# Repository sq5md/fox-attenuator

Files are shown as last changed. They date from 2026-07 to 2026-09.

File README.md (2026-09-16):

# Tłumik odbiorczy do łowów na lisa 
Przedmiotem opisu jest urządzenie do tłumienia sygnału pochodzącego z anteny w celu umożliwienia kierunkowego namierzania bliskich urządzeń nadawczych małej mocy takich jak np. nadajniki do łowów na lisa.

Projekt powstał jako potrzeba klubowa SP5YAM z Komorowa.

Autorzy:

Elektronika + oprogramowanie: **Marcin SQ5MD**

Obudowa: **Michał SP5LEL**

Konsultacje: **Klub SP5YAM**

## Zanim zbudujesz

Zanim zbudujesz, miej na uwadze że PCB v1 zawiera błędy i wymaga **cięcia ścieżek**, dolutowania 3 elementów oraz **poprowadzenia 2 cienkich kynarów do układu QFN**.

Projekt PCB v2 w toku.

## Opis głównych funkcji:

- 2 złącza SMA, jedno do podłączenia anteny, drugie do podłączenia odbiornika.
- Zasilanie z 1 ogniwa 18650
- Wbudowana ładowarka 500mA (USB C)
- Sygnalizacja naładowania na diodzie RGB
- Sygnalizacja tłumienia na diodzie RGB oraz na pasku 5xLED
- Interfejs użytkownika - enkoder kwadraturowy (12 imp na obrót) z przyciskiem
- Tłumienie teoretyczne 0-63dB z krokiem co 0,5dB
- Bypass antenowy 50Ω - do namierzania bez kierunku z bardzo bliskiej odległości
- Tłumienie zmierzone: 2.2-64.2dB (bypass do 80dB)
- Auto Power Off po określonym czasie nieaktywności
- Dioda RGB

## Obsługa

Urządzenie po włączeniu jest od razu gotowe do pracy sygnalizując to zaświeceniem diody LED na zielono.
Kręcenie enkoderem powoduje odpowiednio zwiększenie lub zmniejszenie tłumienia z krokiem 0.5dB. 

Stan tłumienia sygnalizowany jest diodą RGB:
- Intensywny zielony - brak tłumienia
- Zielony-poprzez żółty, pomarańczowy, czerwony - aktywne tłumienie w zależności od koloru LED
- Intensywny czerwony - tłumienie maksymalne
- Niebieski - stan odcięcia anteny. Bypass Z=50Ω.

Urządzenie włączamy i wyłączamy przyciskiem na enkoderze.

Urządzenie posiada wbudowaną ładowarkę (MCP73831), a stan naładowania sygnalizowany jest kolorem fioletowym.

Projekt można przetestować na stoisku SP5YAM w Burzeninie 2026 podczas zabawy w łowy na lisa. Dostępne są 2 sztuki.

## Konstrukcja

Tor antenowy układu składa się z poszczególnych elementów (kolejność od strony podłączania odbiornika):
- Złącze SMA (żeńskie)
- RF-Switch AS179 (rozdziela tor odbiorczy na tor antenowy i bypass Z=50Ω)
	- Do anteny: 2 x cyfrowy tłumik regulowany Berex BDA4601 sterowany z mikrokontrolera
	- Bypass: Rezystancja Z=50Ω, pomija oba tłumiki.

 Układ sterowany jest z mikrokontrolera RP2040 (płyta RP2040-Zero od Waveshare https://www.waveshare.com/wiki/RP2040-Zero )

Interfejs użytkownika stanowi enkoder kwadraturowy z przyciskiem, 5 diod LED, dioda LED RGB.

Urządzenie jest zasilane z jednego ogniwa Li-Ion 18650, oraz posiada wbudowaną ładowarkę MCP73831.

Elementy Q1 i D5 pozwalają zrealizować funkcję programowego wyłączenia urządzenia..

### Schemat
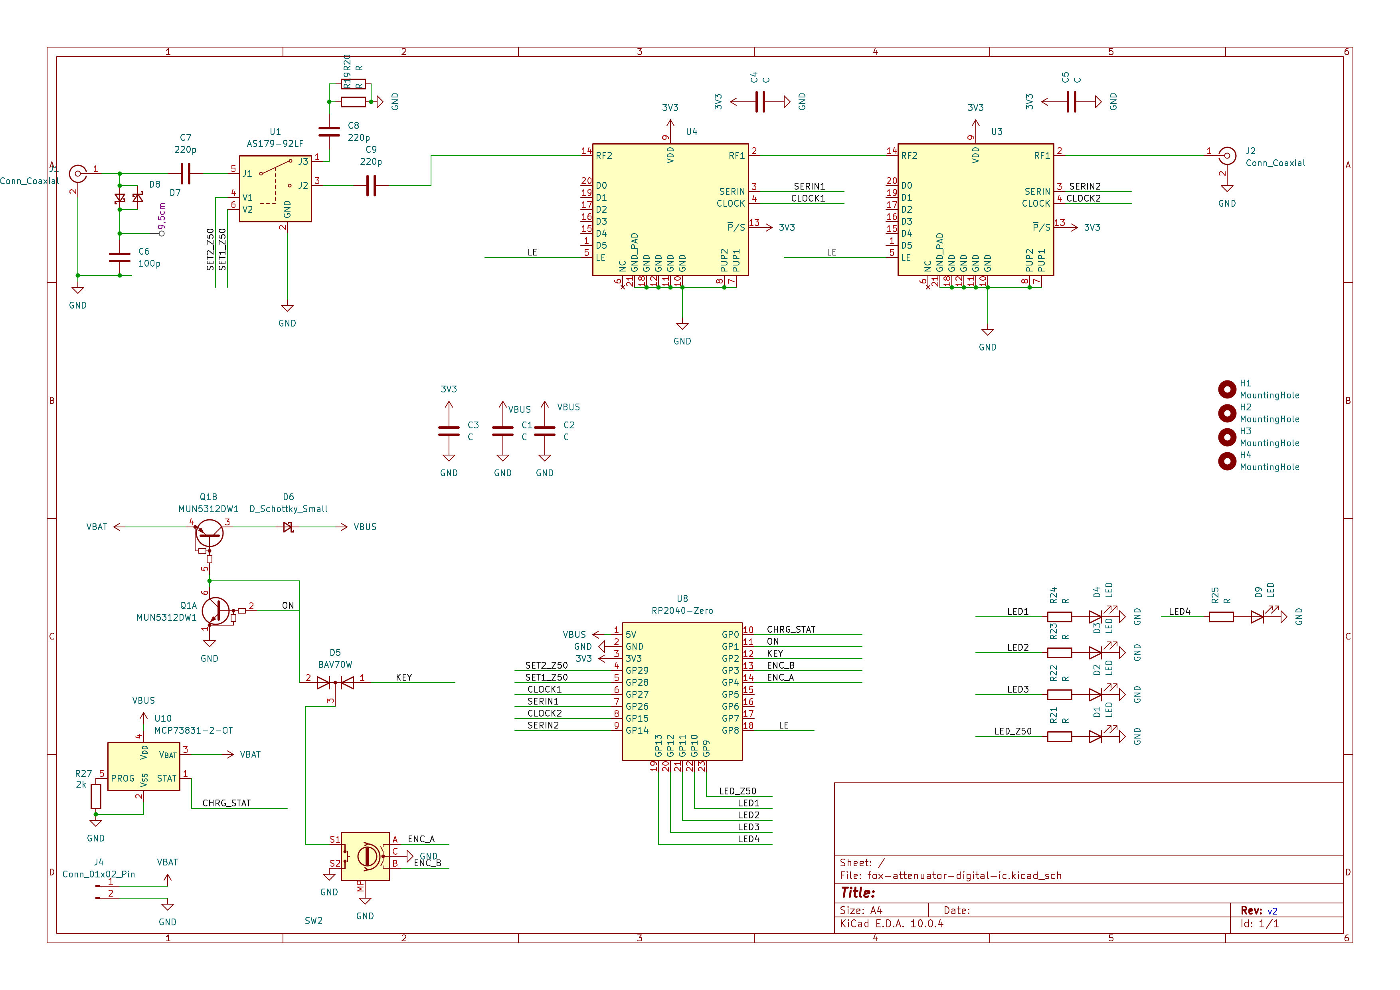
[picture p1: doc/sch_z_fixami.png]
Schemat

### PCB

Płytka drukowana wykonana została w technologii 2 warstwowej na laminacie FR4 o grubości 0.6mm aby zapewnić najlepsze dopasowanie do impedancji 50Ω.

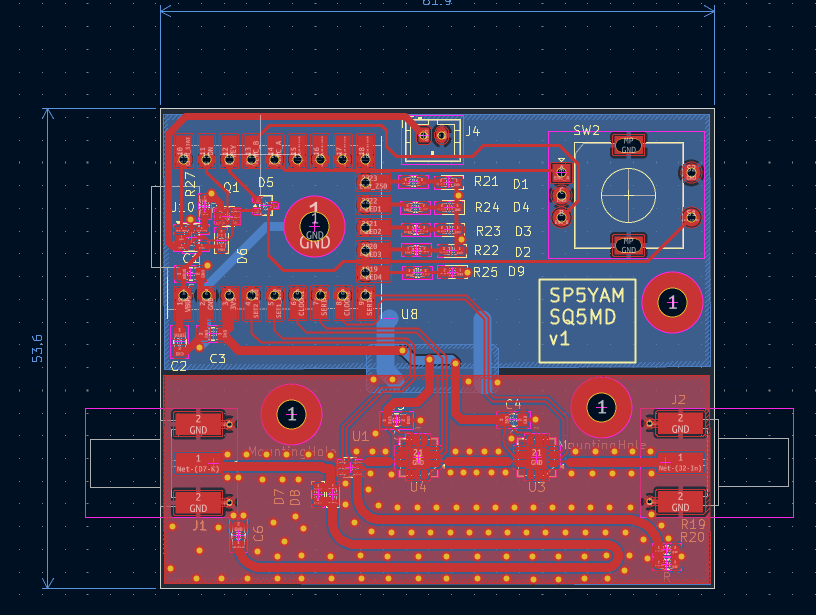
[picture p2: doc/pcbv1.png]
PCB


### Oprogramowanie

#### Moduły

Oprogramowanie układu oparte jest o projekt Zephyr, co przyspieszyło stworzenie projektu. Modułowa konstrukcja oprogramowania pozawala utrzymać porządek i lepiej zrozumieć budowę układu. W układzie można wydzielić kilka głównych modułów które komunikują się ze sobą za pomocą wiadomości wysyłanych przez magistralę EventBus.  
Magistrala EventBus pozwala każdemu z modułów na subskrypcję poszczególnych rodzajów eventów (model Publish/Subscribe).

##### Moduł InputListener

Moduł odpowiada za odpowiedni odczyt eventów z systemu Zephyr i ich wysłanie na magistralę eventów EventBus.
Eventy które wysyła to:
- EncoderRotated(lewo/prawo) - (gdy wykryto przekręcenie enkodera w lewo lub prawo)
- EncoderPressEvent(wciśnięcie/puszczenie) - gdy wyrkryto wciśnięcie lub puszczenie przycisku
- ChargerEvent - gdy wykryto stan naładowania z ładowarki
##### Moduł logiki aplikacji

Obsługuje wiadomości:
- EncoderRotated - wysłanie eventu AttenuatorChange
- EncoderPressEvent - wysłanie eventu PowerOff
- ChargerEvent - wysłanie eventu RgbLedSet()
- AttenuationInfo - wysłanie eventu RgbLedSet oraz LedMatrixSet w zależności od wartości tłumienia

##### Moduł HW
Obsługuje wiadomości:
- LedMatrixSet - ustawienie stanu na diodach 5xLED
- PowerOff - wyłączenie układu
- RgbLedSet - ustawienie odpowiedniego koloru na diodzie RGB
- ApplyAttenuatorChange - zmiana tłumienia (lub bypass)

#### Bootloader
Mikrokontroler posiada wbudowany bootloader.
Aktualizacja oprogramowania jest możliwa za pomocą przewodu USB-C.
Jest to standardowy bootloader wbudowany w mikrokontroler RP2040.

### Obudowa

Do układu powstała obudowa wykonana w technologii druku 3D FDM, autorem obudowy jest Michał SP5LEL.
Na moment pisania tej treści nie ma dostępnych fotografii obudowy.

### Fotografie

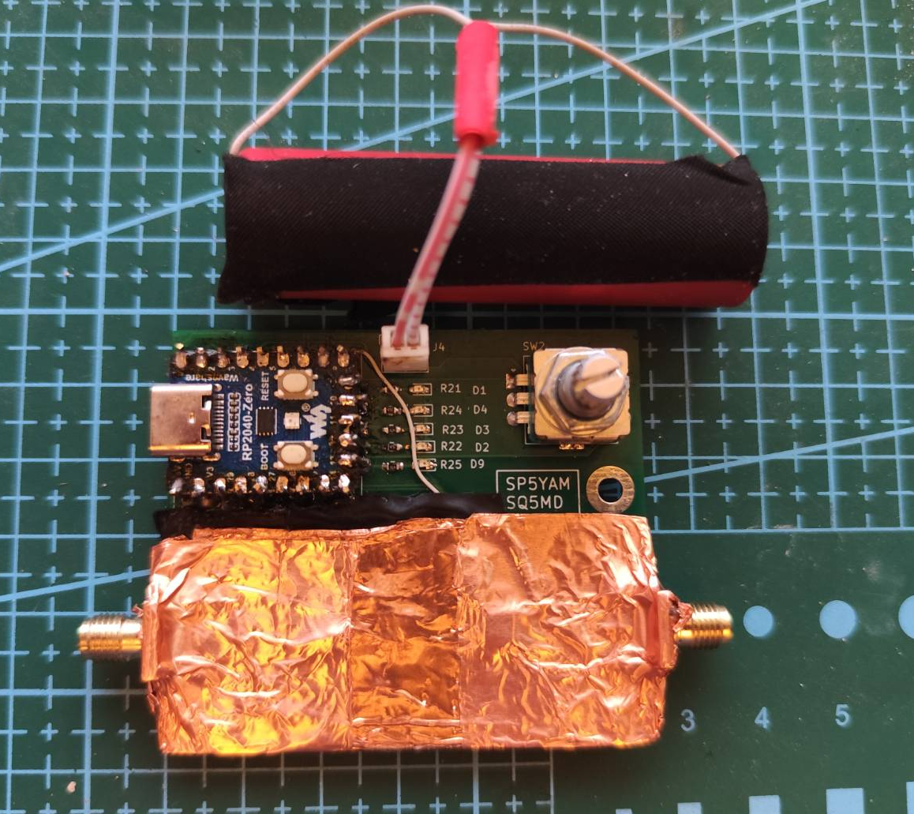
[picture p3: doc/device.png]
Urządzenie


## Pomiary

Urządzenie pomiarowe:
NanoVNA V2 od NanoRFE (https://nanorfe.com/pl/)
Aplikacja:
VNA_View na Linux

Parametry pomiarowe:
Sweep 144-440MHz, 1024 punkty, AVG=5
kalibracja SOLT

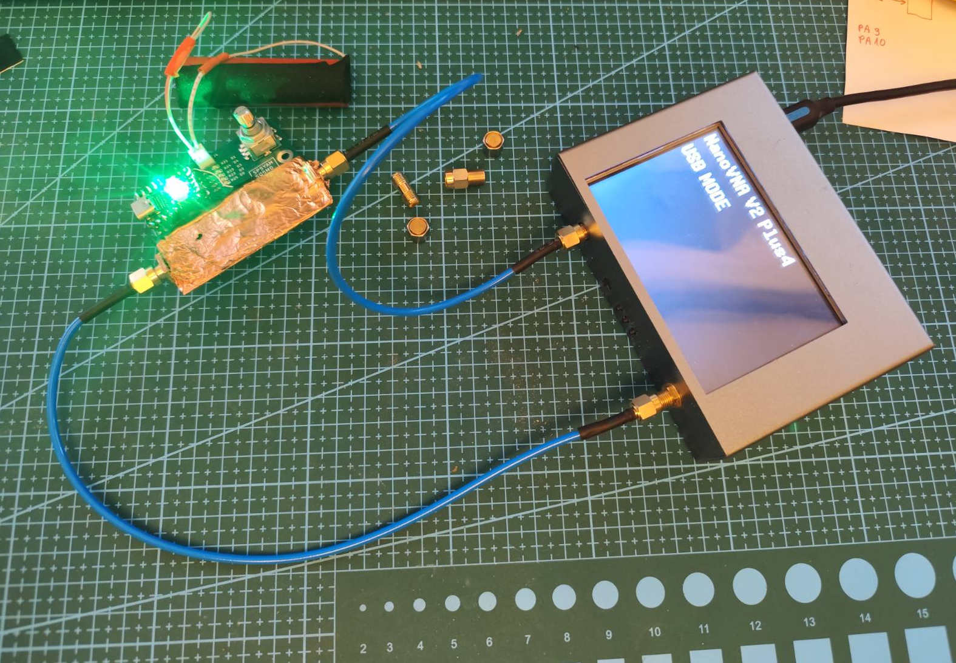
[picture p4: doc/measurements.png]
Pomiary


### Minimalne tłumienie
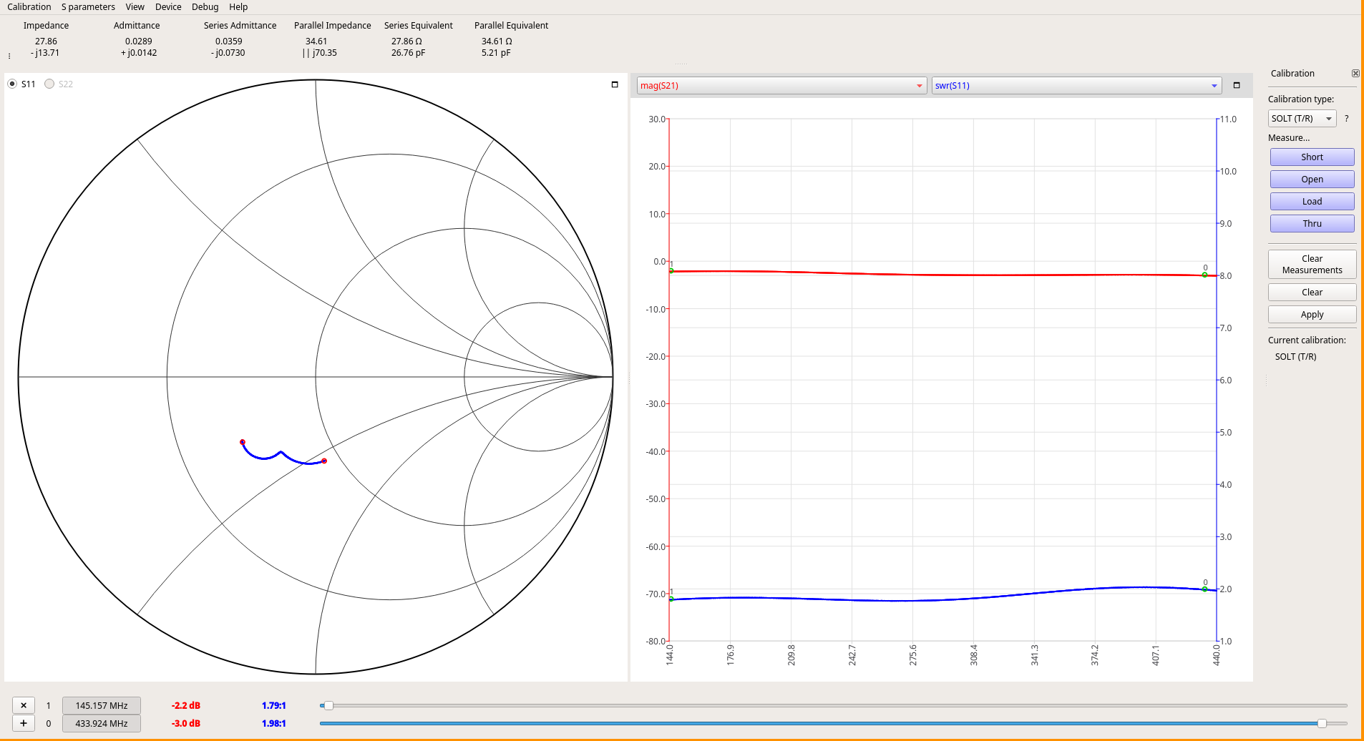
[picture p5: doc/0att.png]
Minimalne tłumienie

### Połowa skali
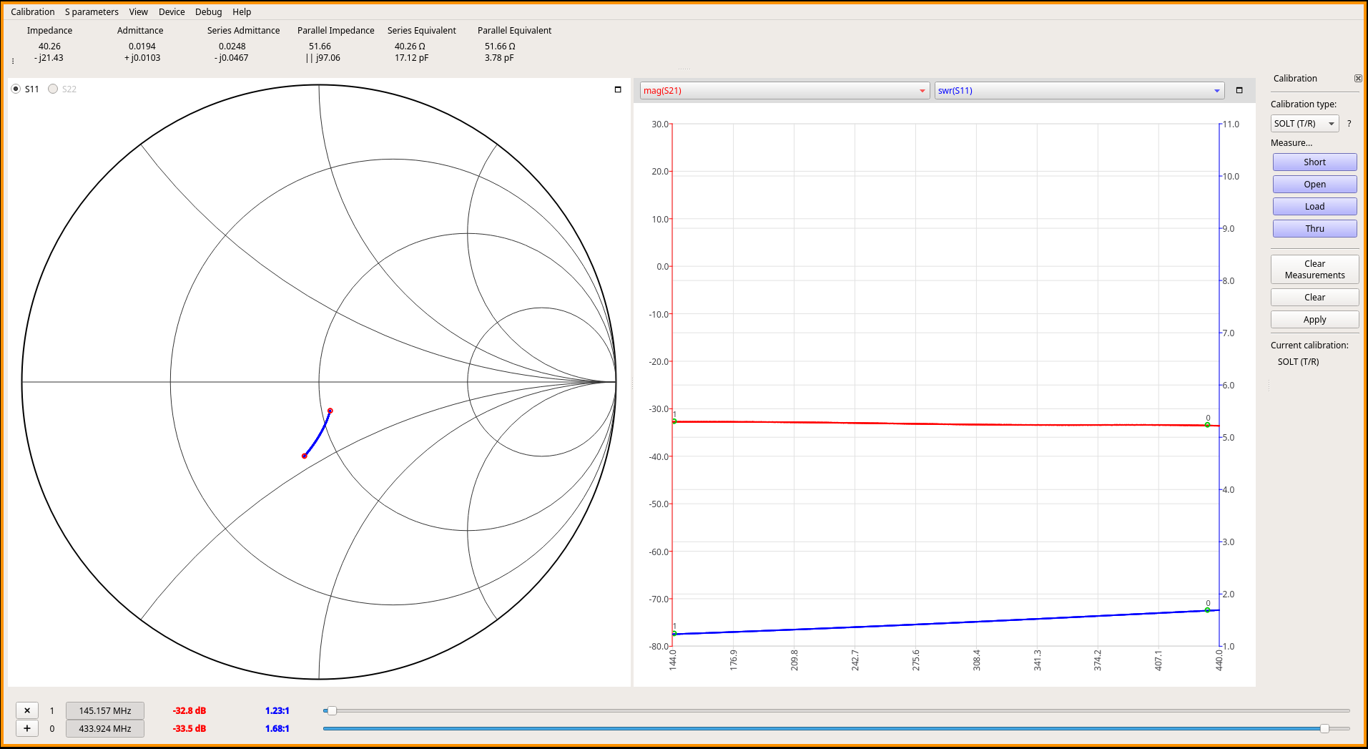
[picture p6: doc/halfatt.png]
Połowa tłumienia

### Maksymalne tłumienie
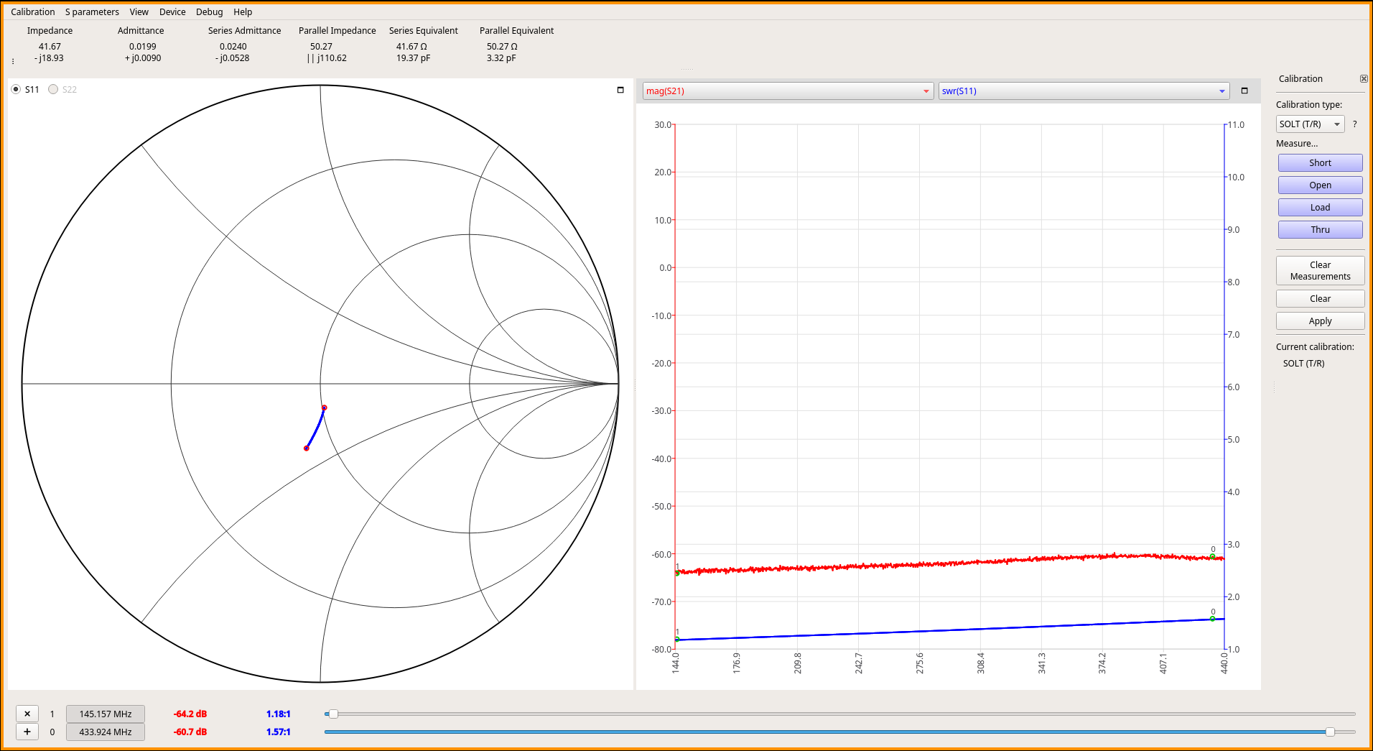
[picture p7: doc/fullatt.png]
Maksymalne tłumienie

### Bypass
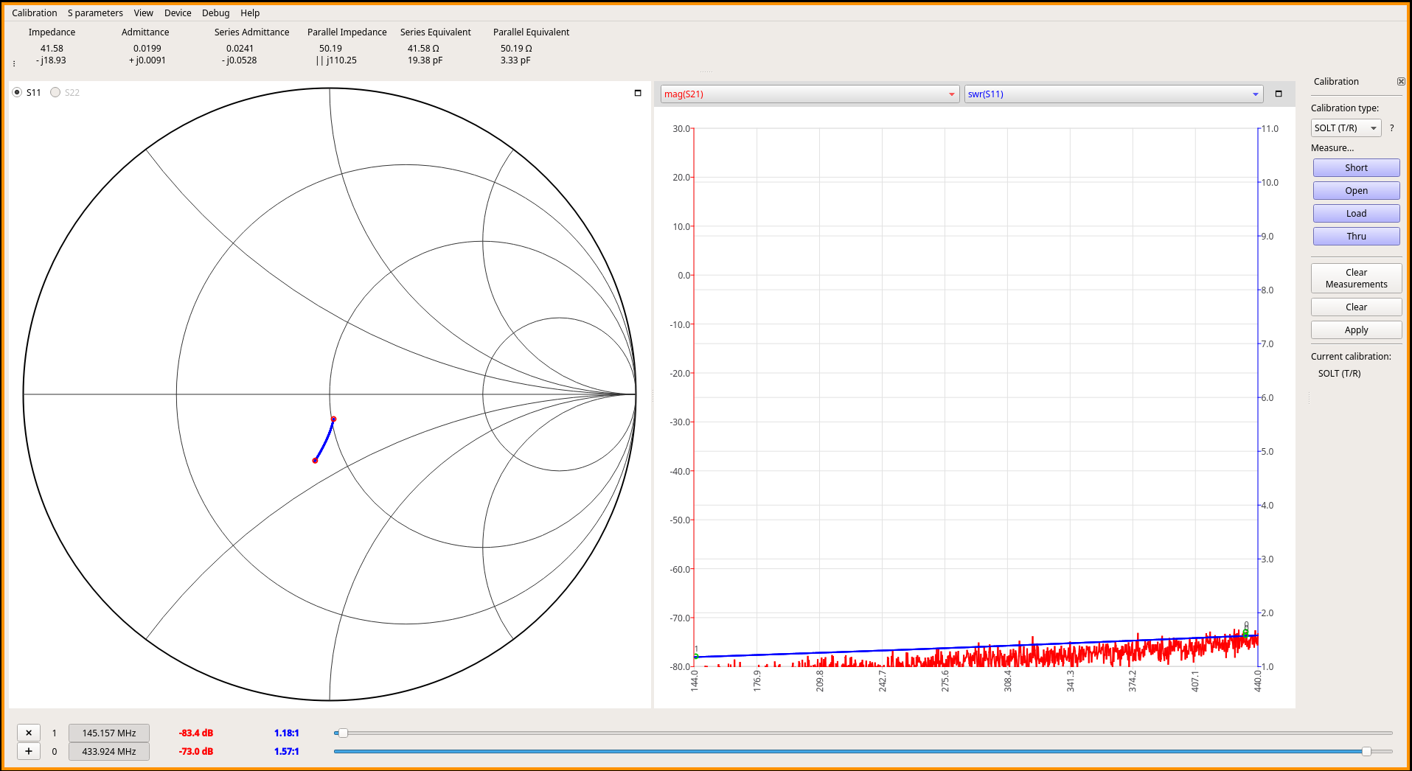
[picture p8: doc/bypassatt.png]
Bypass antenowy


Tor bypassu jest najbardziej wrażliwy na ekranowanie urządzenia.

## TODO:

- [ ] Poprawki PCB: brak sygnału LE, brak DC-blockerów RF
- [ ] Diody LED THT zamiast SMD
- [ ] Tylko jeden tłumik regulowany, drugi stały 30dB
- [ ] Wymiana ładowarki jest bardzo trudna - montować układ inaczej
- [ ] Integracja z odbiornikiem (żeby nie trzeba było podłączać zewnętrznego odbiornika)
- [ ] Dodać pomiar napięcia baterii
- [ ] Wrzucić do releases plik uf2

## Przeróbka PCB v1 aby działała

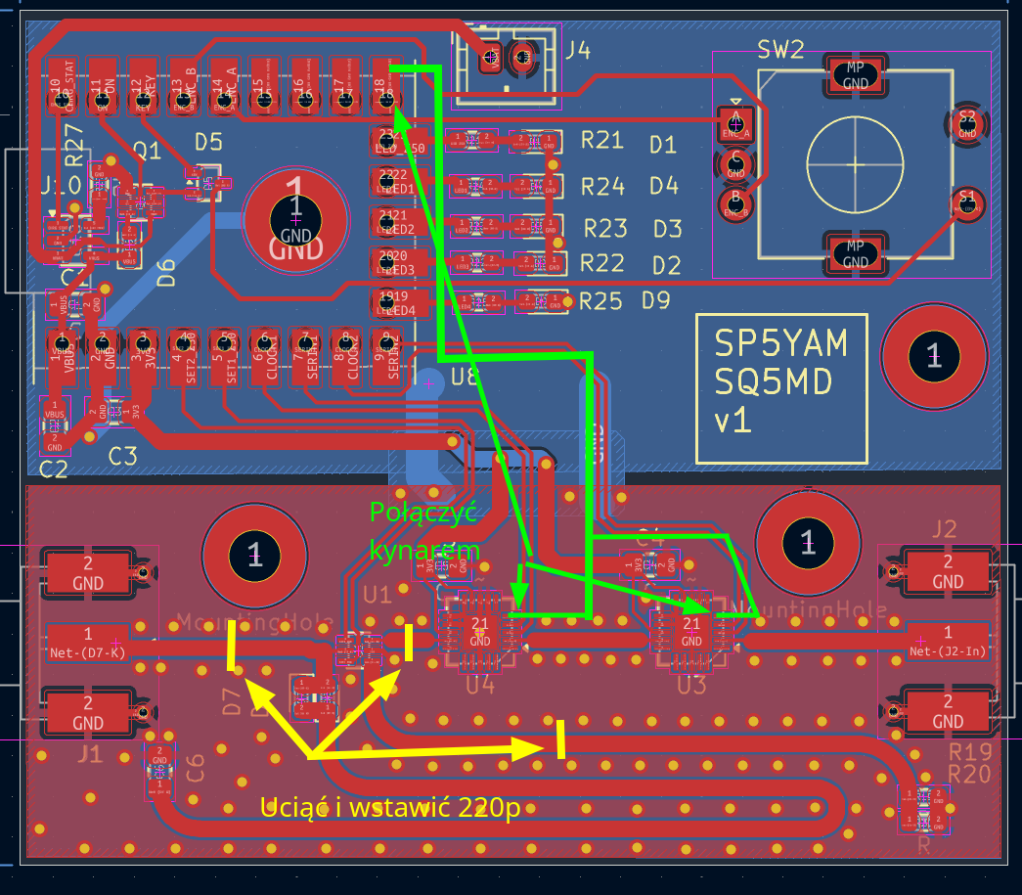
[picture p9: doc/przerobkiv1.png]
Przeróbka v1


## Edytor schematów i pcb

Stworzone w Kicad 10.0.4

## Jak skompilować

1. Zainstaluj Zephyra: https://docs.zephyrproject.org/latest/develop/getting_started/index.html
2. Zainstaluj i skonfiguruj CLion: https://docs.zephyrproject.org/latest/develop/tools/clion.html
3. Otwórz projekt in CLion, otwórz folder w którym znajduje się główny plik CMakeLists.txt (w momencie pisania tej treści jest to folder 'software/fox-attenuator')
4. Uruchom płytkę RP2040-Zero w trybie bootloadera a następnie wybierz target "flash" w CLion i uruchom budowanie projektu.

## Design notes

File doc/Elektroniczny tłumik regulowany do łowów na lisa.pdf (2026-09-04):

## Elektroniczny tłumik regulowany do łowów na lisa

Przedmiotem opisu jest urządzenie do tłumienia sygnału pochodzącego z anteny w celu umożliwienia kierunkowego namierzania bliskich urządzeń nadawczych małej mocy takich jak np. nadajniki do łowów na lisa.
Projekt powstał jako potrzeba klubowa SP5YAM z Komorowa.

Autorzy:
Elektronika + oprogramowanie: Marcin SQ5MD
Obudowa: Michał SP5LEL
Konsultacje: Klub SP5YAM

Link: https://github.com/sq5md/fox-attenuator

## Opis głównych funkcji:

## Obsługa

Urządzenie po włączeniu jest od razu gotowe do pracy sygnalizując to zaświeceniem diody LED na zielono.
Kręcenie enkoderem powoduje odpowiednio zwiększenie lub zmniejszenie tłumienia z krokiem 0.5dB.

Stan tłumienia sygnalizowany jest diodą RGB:

Urządzenie włączamy i wyłączamy przyciskiem na enkoderze.

2 złącza SMA, jedno do podłączenia anteny, drugie do podłączenia odbiornika. Zasilanie z 1 ogniwa 18650
Wbudowana ładowarka 500mA (USB C)
Sygnalizacja naładowania na diodzie RGB
Sygnalizacja tłumienia na diodzie RGB oraz na pasku 5xLED
Interfejs użytkownika - enkoder kwadraturowy (12 imp na obrót) z przyciskiem Tłumienie teoretyczne 0-63dB z krokiem co 0,5dB
Bypass antenowy 50Ω - do namierzania bez kierunku z bardzo bliskiej odległości Tłumienie zmierzone: 2.2-64.2dB (bypass do 80dB)
Auto Power Off po określonym czasie nieaktywności
Dioda RGB

Intensywny zielony - brak tłumienia
Zielony-poprzez żółty, pomarańczowy, czerwony - aktywne tłumienie w zależności od koloru LED
Intensywny czerwony - tłumienie maksymalne
Niebieski - stan odcięcia anteny. Bypass Z=50Ω.

Urządzenie posiada wbudowaną ładowarkę (MCP73831), a stan naładowania sygnalizowany jest kolorem fioletowym.

Projekt można przetestować na stoisku SP5YAM w Burzeninie 2026 podczas zabawy w łowy na lisa. Dostępne są 2 sztuki.

## Konstrukcja

Tor antenowy układu składa się z poszczególnych elementów (kolejność od strony podłączania odbiornika):

Układ sterowany jest z mikrokontrolera RP2040 (płyta RP2040-Zero od Waveshare https://www.waveshare.com/wiki/RP2040-Zero )

Interfejs użytkownika stanowi enkoder kwadraturowy z przyciskiem, 5 diod LED, dioda LED RGB.

Urządzenie jest zasilane z jednego ogniwa Li-Ion 18650, oraz posiada wbudowaną ładowarkę MCP73831.

Elementy Q1 i D5 pozwalają zrealizować funkcję programowego wyłączenia urządzenia..

### Schemat

Złącze SMA (żeńskie)
RF-Switch AS179 (rozdziela tor odbiorczy na tor antenowy i bypass Z=50Ω) Do anteny: 2 x cyfrowy tłumik regulowany Berex BDA4601 sterowany z mikrokontrolera
Bypass: Rezystancja Z=50Ω, pomija oba tłumiki.

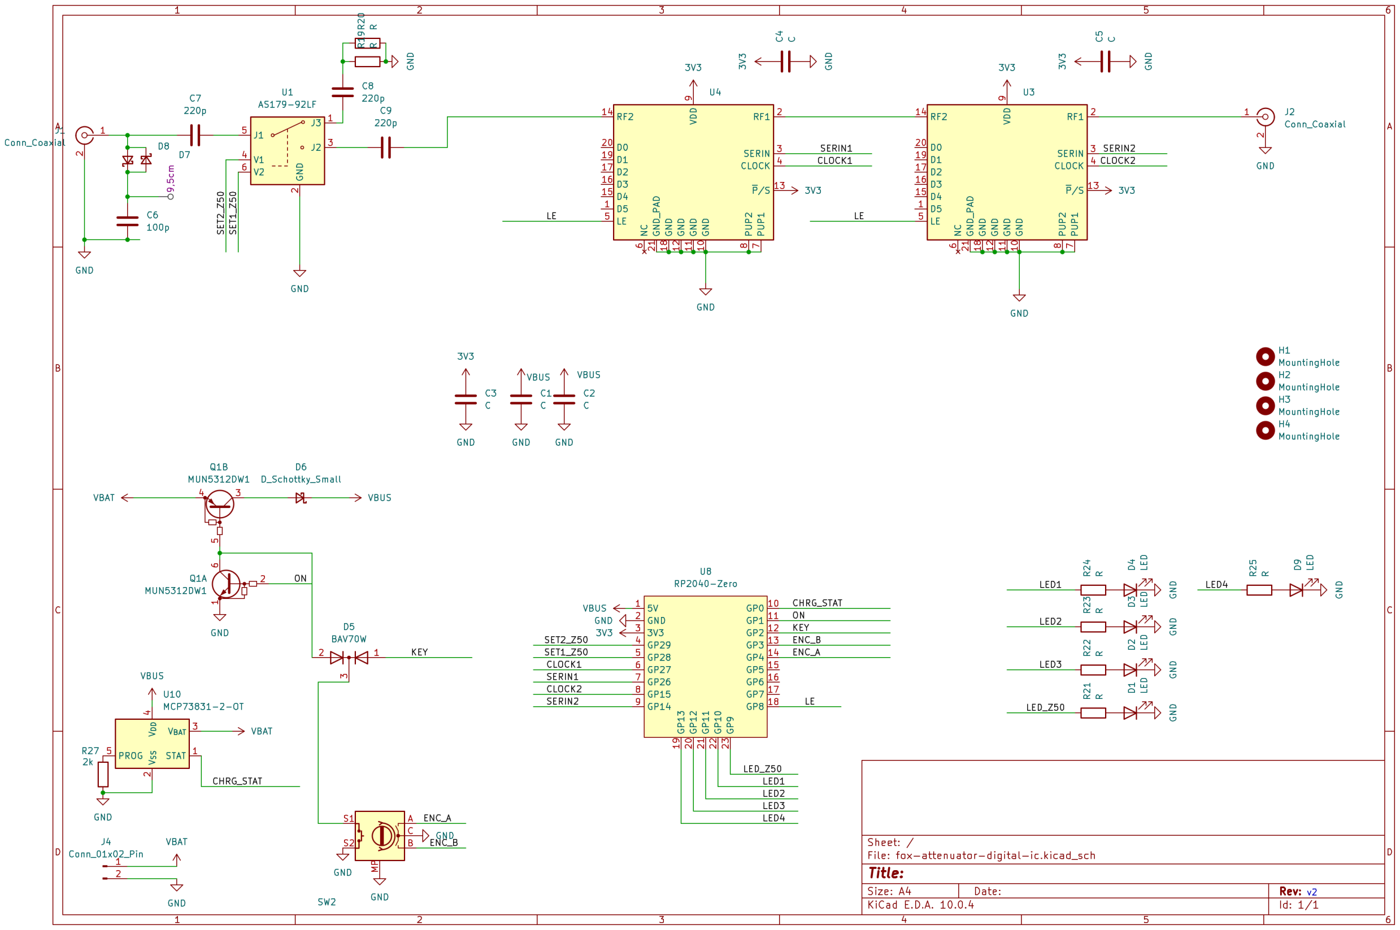
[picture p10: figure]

### PCB

Płytka drukowana wykonana została w technologii 2 warstwowej na laminacie FR4 o grubości 0.6mm aby zapewnić najlepsze dopasowanie do impedancji 50Ω.

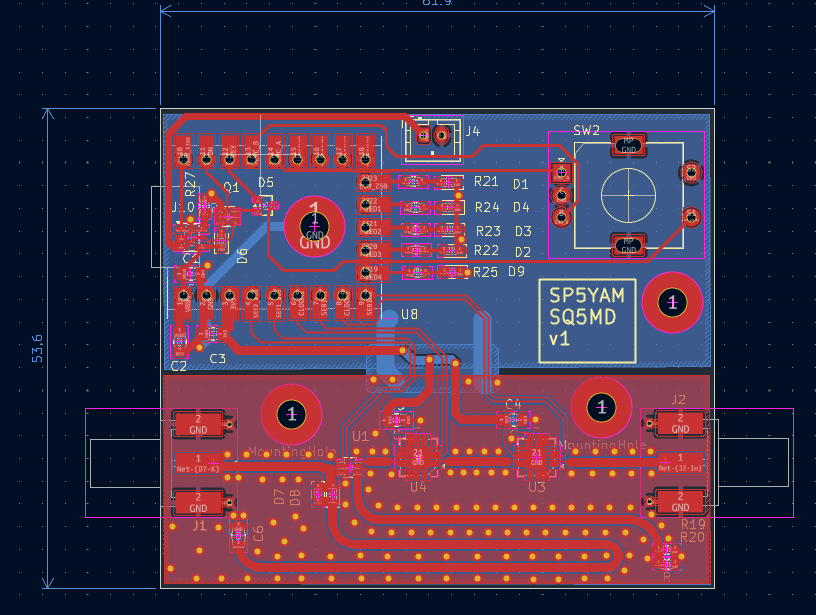
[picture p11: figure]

### Oprogramowanie

### Moduły

Oprogramowanie układu oparte jest o projekt Zephyr, co przyspieszyło stworzenie projektu. Modułowa konstrukcja oprogramowania pozawala utrzymać porządek i lepiej zrozumieć budowę układu. W układzie można wydzielić kilka głównych modułów które komunikują się ze sobą za pomocą wiadomości wysyłanych przez magistralę EventBus.
Magistrala EventBus pozwala każdemu z modułów na subskrypcję poszczególnych rodzajów eventów (model Publish/Subscribe).

Moduł InputListener

Moduł odpowiada za odpowiedni odczyt eventów z systemu Zephyr i ich wysłanie na magistralę eventów EventBus.
Eventy które wysyła to:

Moduł logiki aplikacji

EncoderRotated(lewo/prawo) - (gdy wykryto przekręcenie enkodera w lewo lub prawo) EncoderPressEvent(wciśnięcie/puszczenie) - gdy wyrkryto wciśnięcie lub puszczenie przycisku
ChargerEvent - gdy wykryto stan naładowania z ładowarki

Obsługuje wiadomości:

Moduł HW

Obsługuje wiadomości:

### Bootloader

Mikrokontroler posiada wbudowany bootloader.
Aktualizacja oprogramowania jest możliwa za pomocą przewodu USB-C. Jest to standardowy bootloader wbudowany w mikrokontroler RP2040.

### Obudowa

Do układu powstała obudowa wykonana w technologii druku 3D FDM, autorem obudowy jest Michał SP5LEL.
Na moment pisania tej treści nie ma dostępnych fotografii obudowy.

### Fotografie

EncoderRotated - wysłanie eventu AttenuatorChange
EncoderPressEvent - wysłanie eventu PowerOff
ChargerEvent - wysłanie eventu RgbLedSet()
AttenuationInfo - wysłanie eventu RgbLedSet oraz LedMatrixSet w zależności od wartości tłumienia

LedMatrixSet - ustawienie stanu na diodach 5xLED
PowerOff - wyłączenie układu
RgbLedSet - ustawienie odpowiedniego koloru na diodzie RGB ApplyAttenuatorChange - zmiana tłumienia (lub bypass)

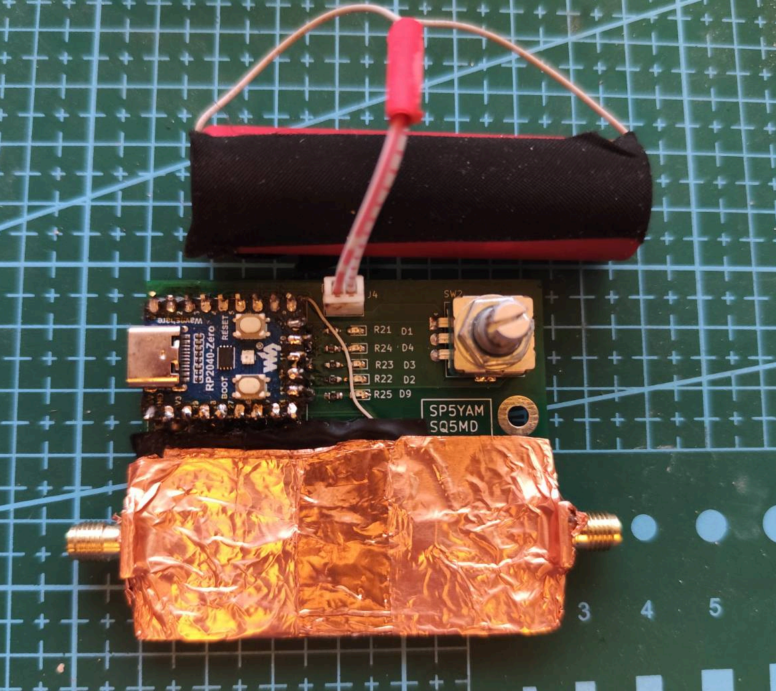
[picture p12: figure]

## Pomiary

Urządzenie pomiarowe:
NanoVNA V2 od NanoRFE (https://nanorfe.com/pl/) Aplikacja:
VNA_View na Linux

Parametry pomiarowe:
Sweep 144-440MHz, 1024 punkty, AVG=5 kalibracja SOLT

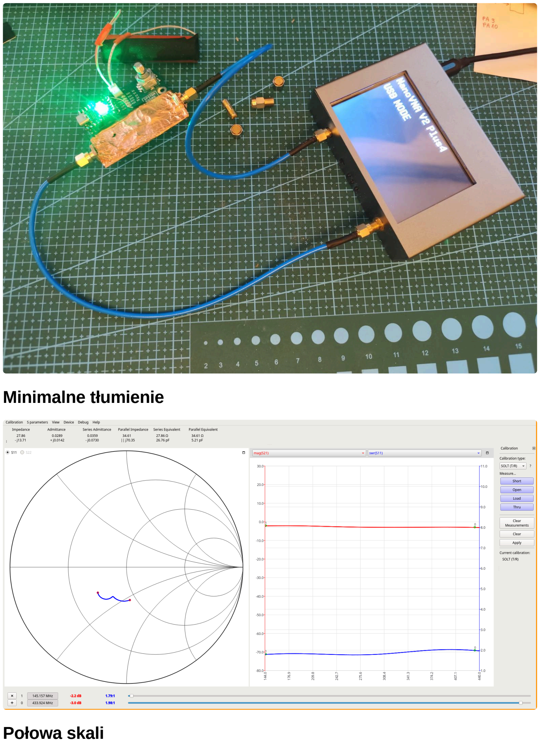
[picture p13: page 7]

### Minimalne tłumienie

### Połowa skali

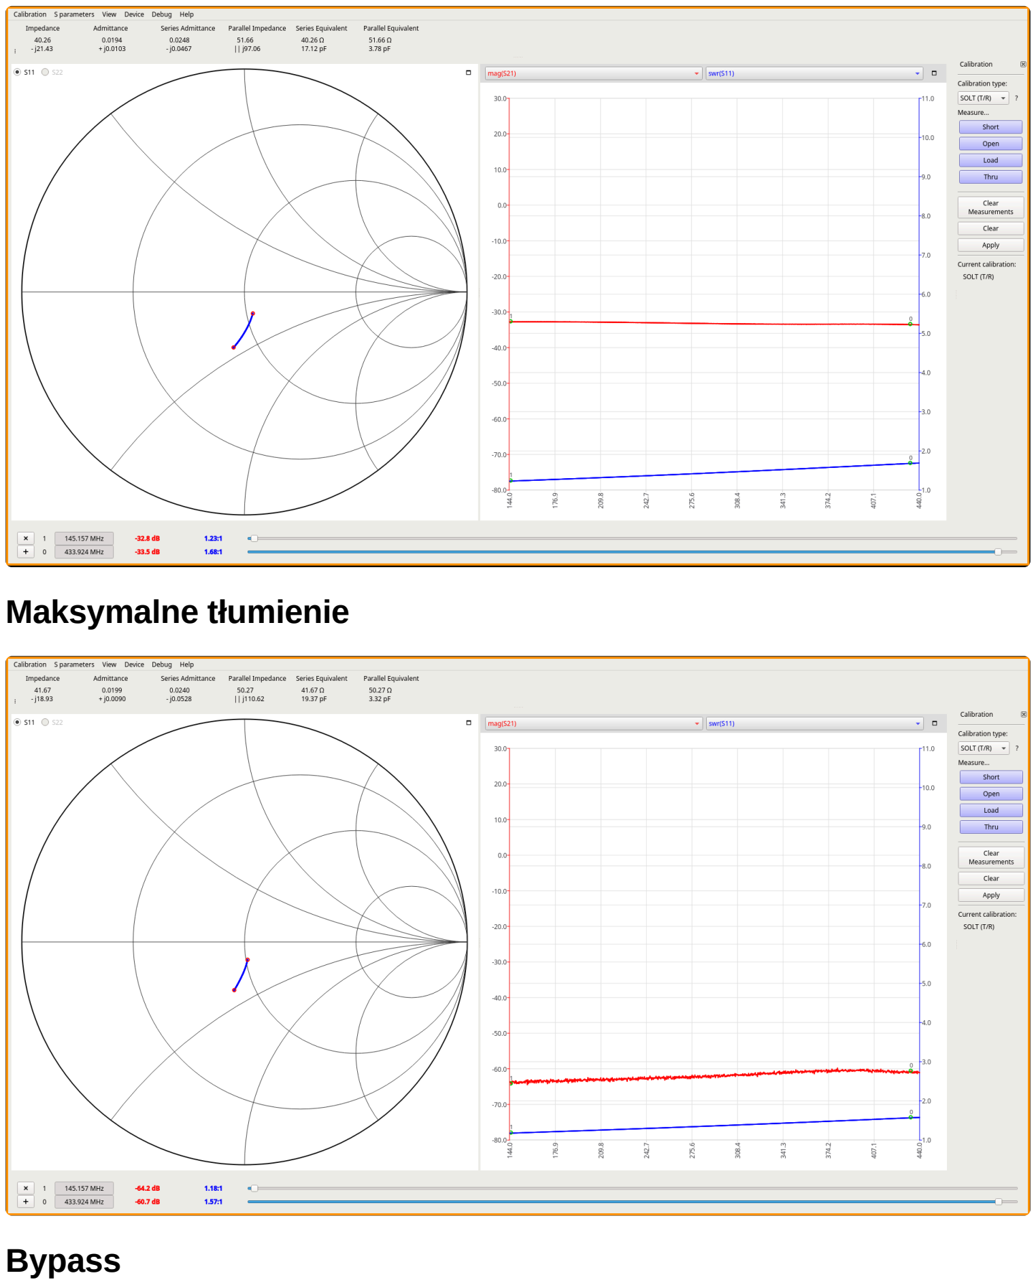
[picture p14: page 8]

### Maksymalne tłumienie

### Bypass

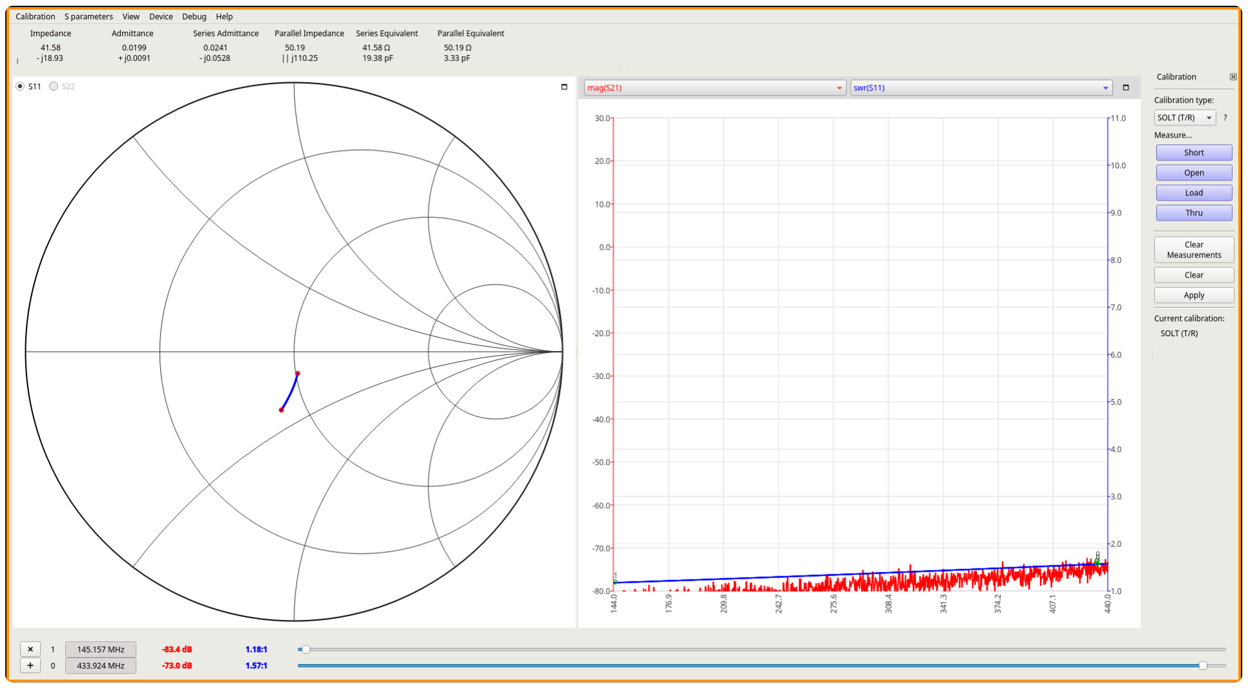
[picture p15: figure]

Tor bypassu jest najbardziej wrażliwy na ekranowanie urządzenia.

## Plany na przyszłość

Poprawki PCB: brak sygnału LE, brak DC-blockerów RF
Diody LED THT zamiast SMD
Tylko jeden tłumik regulowany, drugi stały 30dB
Wymiana ładowarki jest bardzo trudna - montować układ inaczej
Integracja z odbiornikiem (żeby nie trzeba było podłączać zewnętrznego odbiornika) Dodać pomiar napięcia baterii

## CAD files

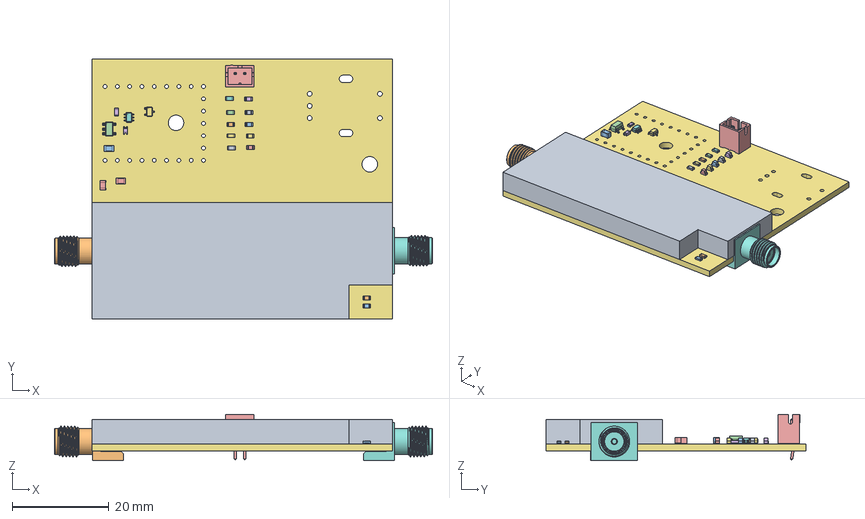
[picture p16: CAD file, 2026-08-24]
3d/shield.FCStd
78.0 x 53.6 x 9.58 mm
SMA_Molex_73251-1153_EdgeMount_Horizontal
LED_0603_1608Metric
D_0603
C_0805_2012Metric
D_0604
SOT-323_SC-70
SMA_Molex_73251-1153_EdgeMount_Horizontal002
D_0605
R_0603_1608Metric
SOT-363_SC-70-6
R_0603_1608Metric002
C_0805_2012Metric002
LED_0603_1608Metric002
LED_0603_1608Metric004
SOT-363_SC-70-002
R_0603_1608Metric004
R_0603_1608Metric006
C_0805_2012Metric004
SOT-23-5
LED_0603_1608Metric006
R_0603_1608Metric008
R_0603_1608Metric010
R_0603_1608Metric012
LED_0603_1608Metric008
C_0805_2012Metric006
R_0603_1608Metric014
C_0805_2012Metric008
JST_B2B_PH_K
C_0805_2012Metric010
fox-attenuator-digital-ic_PCB

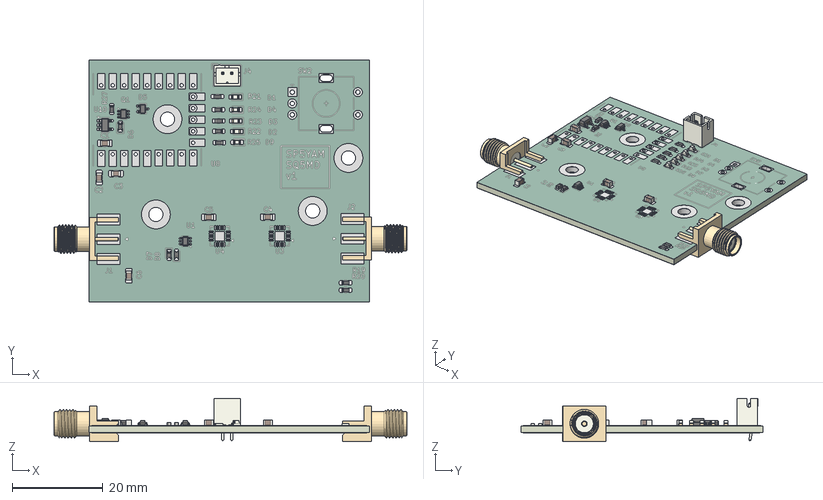
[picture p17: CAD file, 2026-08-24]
3d/fox-attenuator-v1.step
78.0 x 53.6 x 9.58 mm
SMA_Molex_73251-1153_EdgeMount_Horizontal x 2
LED_0603_1608Metric x 5
D_0603 x 3
C_0805_2012Metric x 6
SOT-323_SC-70
R_0603_1608Metric x 8
SOT-363_SC-70-6 x 2
SOT-23-5
JST_B2B_PH_K
fox-attenuator-digital-ic_copper
fox-attenuator-digital-ic_pad
fox-attenuator-digital-ic_via
fox-attenuator-digital-ic_silkscreen
fox-attenuator-digital-ic_soldermask x 2
fox-attenuator-digital-ic_PCB

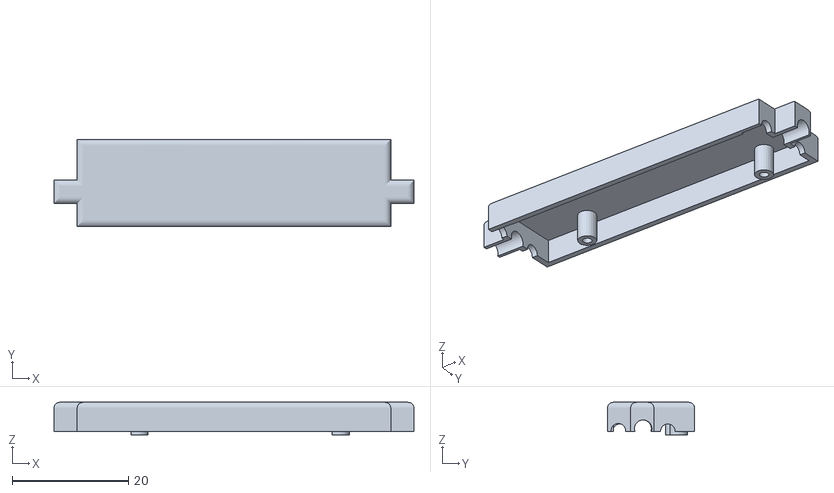
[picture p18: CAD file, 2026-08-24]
3d/shield-Body.stl
62.0 x 15.0 x 5.60

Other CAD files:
3d/shield_simple.FCStd

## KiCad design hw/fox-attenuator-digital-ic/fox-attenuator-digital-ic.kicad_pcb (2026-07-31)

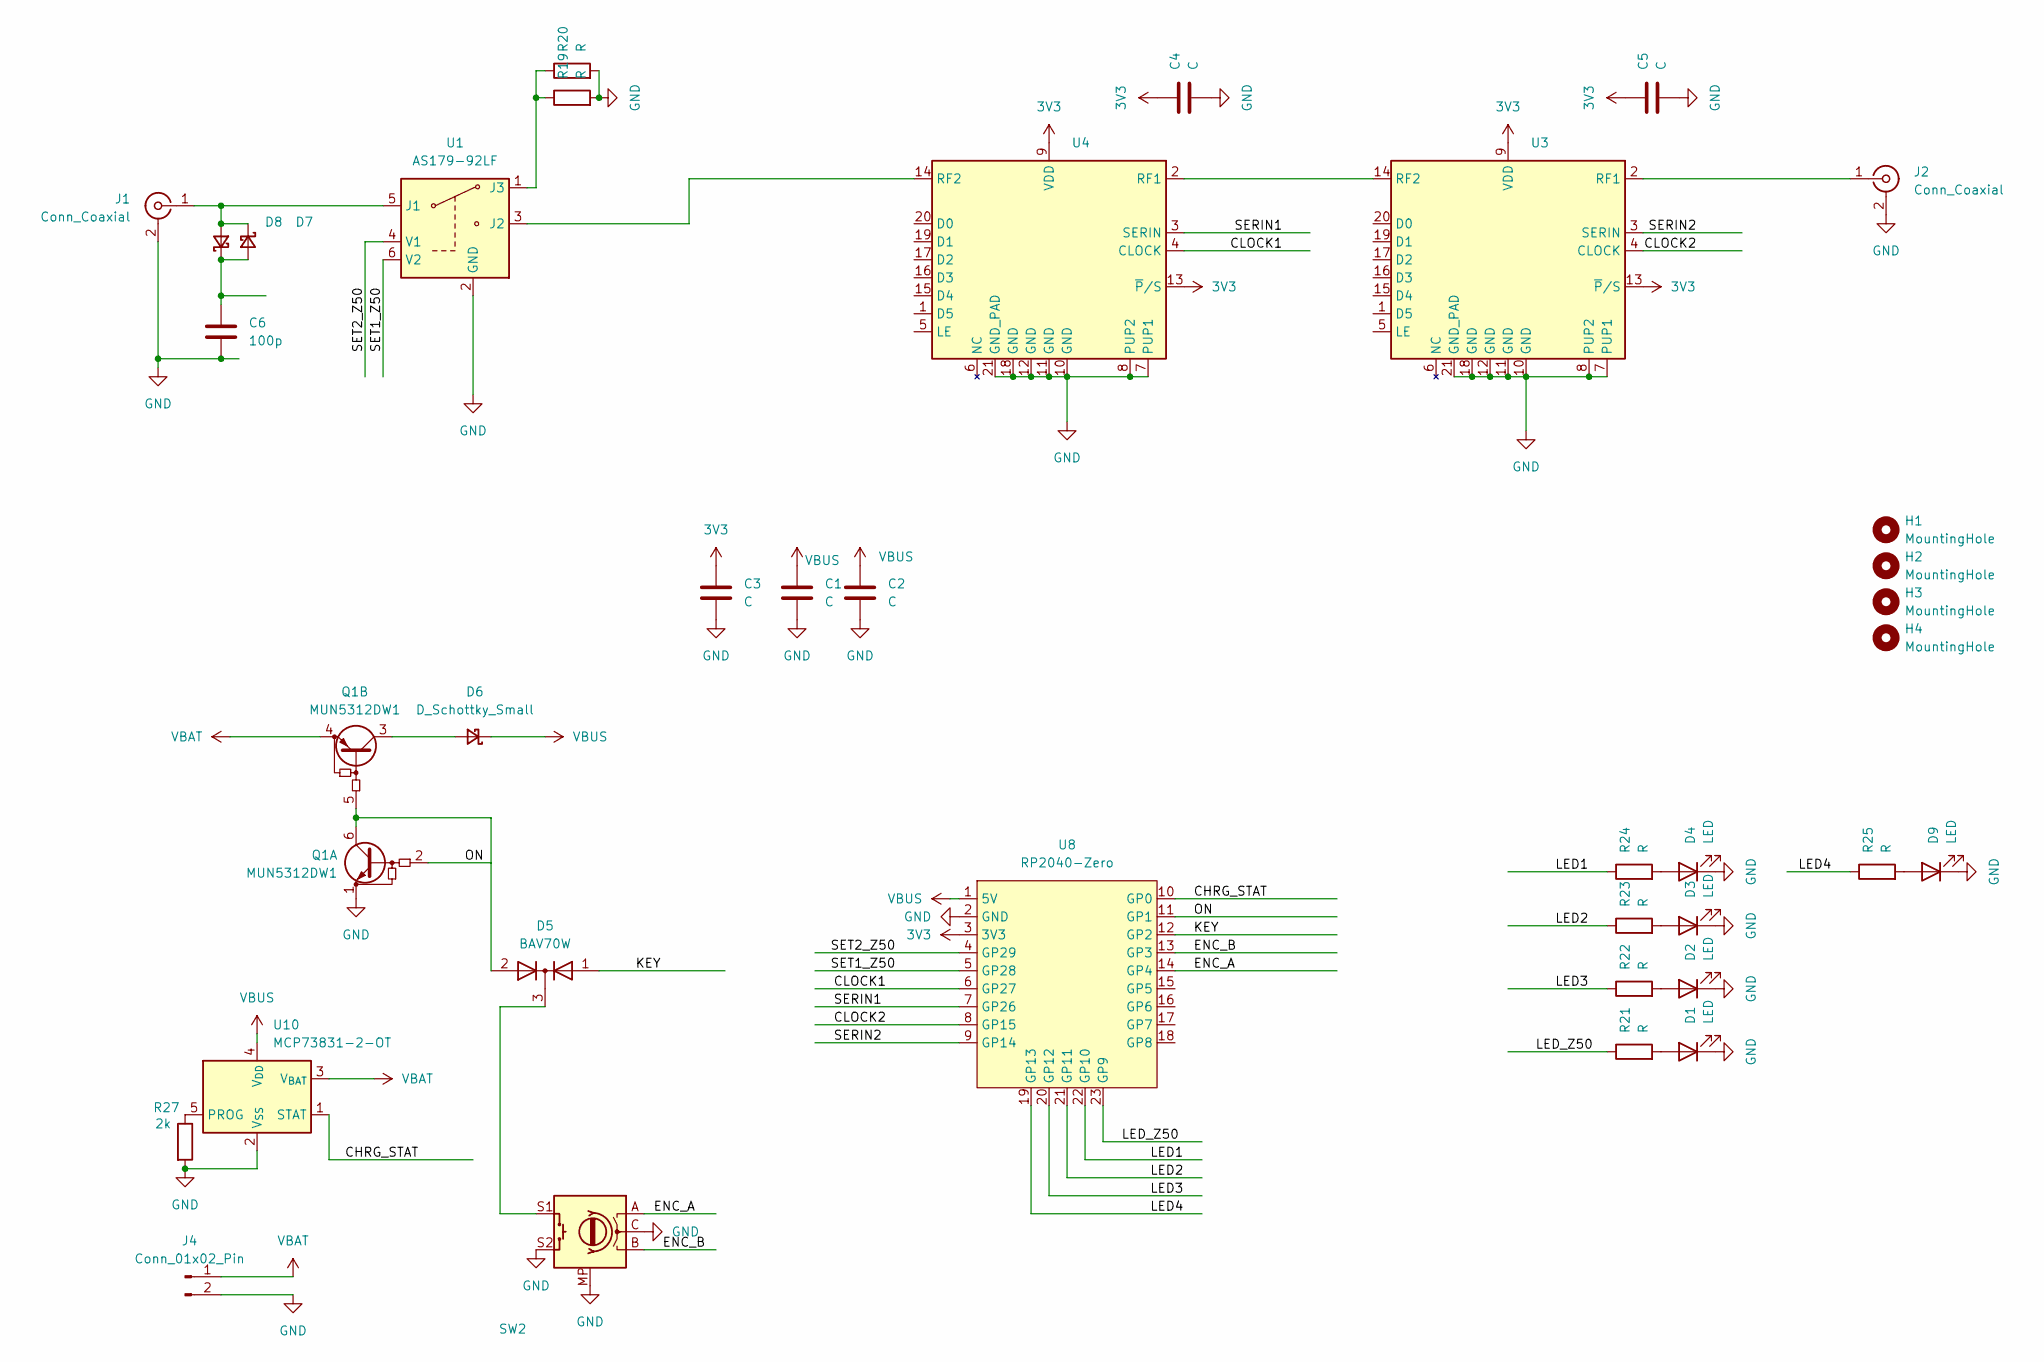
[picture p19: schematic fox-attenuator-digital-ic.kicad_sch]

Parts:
C1, C2, C3, C4, C5: C; C_0805_2012Metric_Pad1.18x1.45mm_HandSolder
C6: 100p; C_0805_2012Metric_Pad1.18x1.45mm_HandSolder
D1, D2, D3, D4, D9: LED; LED_0603_1608Metric_Pad1.05x0.95mm_HandSolder
D5: BAV70W; SOT-323_SC-70
D6, D7, D8: D_Schottky_Small; D_0603_1608Metric
H1, H2, H3, H4: MountingHole; MountingHole_3.2mm_M3_Pad_TopBottom
J1, J2: Conn_Coaxial; SMA_Molex_73251-1153_EdgeMount_Horizontal
J4: Conn_01x02_Pin; JST_PH_B2B-PH-K_1x02_P2.00mm_Vertical
Q1: MUN5312DW1; SOT-363_SC-70-6
R19, R20, R21, R22, R23, R24, R25: R; R_0603_1608Metric_Pad0.98x0.95mm_HandSolder
R27: 2k; R_0603_1608Metric
SW2: RotaryEncoder_Switch_MP; RotaryEncoder_Alps_EC11E-Switch_Vertical_H20mm
U1: AS179-92LF; SOT-363_SC-70-6
U3, U4: TQFN-20-1EP_4x4mm_P0.5mm_EP2.1x2.1mm
U8: RP2040-Zero; RP2040 Zero
U10: MCP73831-2-OT; SOT-23-5

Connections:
3V3: C3.1, C4.1, C5.1, U3.9 (VDD), U3.13 (~P/S), U4.9 (VDD), U4.13 (~P/S), U8.3 (3V3)
/CHRG_STAT: U8.10 (GP0), U10.1 (STAT)
/CLOCK1: U4.4 (CLOCK), U8.6 (GP27)
/CLOCK2: U3.4 (CLOCK), U8.8 (GP15)
/ENC_A: SW2.A, U8.14 (GP4)
/ENC_B: SW2.B, U8.13 (GP3)
/KEY: D5.1 (A), U8.12 (GP2)
/LED1: R24.1, U8.22 (GP10)
/LED2: R23.1, U8.21 (GP11)
/LED3: R22.1, U8.20 (GP12)
/LED4: R25.1, U8.19 (GP13)
/LED_Z50: R21.1, U8.23 (GP9)
/ON: Q1.2 (B1), U8.11 (GP1)
/SERIN1: U4.3 (SERIN), U8.7 (GP26)
/SERIN2: U3.3 (SERIN), U8.9 (GP14)
/SET1_Z50: U1.6 (V2), U8.5 (GP28)
/SET2_Z50: U1.4 (V1), U8.4 (GP29)
GND: C1.2, C2.2, C3.2, C4.2, C5.2, C6.2, D1.1 (K), D2.1 (K), D3.1 (K), D4.1 (K), D9.1 (K), H3.1, J1.2 (Ext), J2.2 (Ext), J4.2, Q1.1 (E1), R19.2, R20.2, R27.2, SW2.C, SW2.MP, SW2.S2, U1.2 (GND), U3.7 (PUP1), U3.8 (PUP2), U3.10 (GND), U3.11 (GND), U3.12 (GND), U3.18 (GND), U3.21 (GND_PAD), U4.7 (PUP1), U4.8 (PUP2), U4.10 (GND), U4.11 (GND), U4.12 (GND), U4.18 (GND), U4.21 (GND_PAD), U8.2 (GND), U10.2 (V_{SS})
unnamed: D1.2 (A), R21.2
unnamed: D2.2 (A), R22.2
unnamed: D3.2 (A), R23.2
unnamed: D4.2 (A), R24.2
unnamed: D5.3 (K), SW2.S1
unnamed: D6.2 (A), Q1.3 (C2)
unnamed: C6.1, D7.2 (A), D8.1 (K)
unnamed: D7.1 (K), D8.2 (A), J1.1 (In), U1.5 (J1)
unnamed: D9.2 (A), R25.2
unnamed: J2.1 (In), U3.2 (RF1)
unnamed: D5.2 (A), Q1.5 (B2), Q1.6 (C1)
unnamed: U1.3 (J2), U4.14 (RF2)
unnamed: R19.1, R20.1, U1.1 (J3)
unnamed: U3.14 (RF2), U4.2 (RF1)
unnamed: R27.1, U10.5 (PROG)
VBAT: J4.1, Q1.4 (E2), U10.3 (V_{BAT})
VBUS: C1.1, C2.1, D6.1 (K), U8.1 (5V), U10.4 (V_{DD})

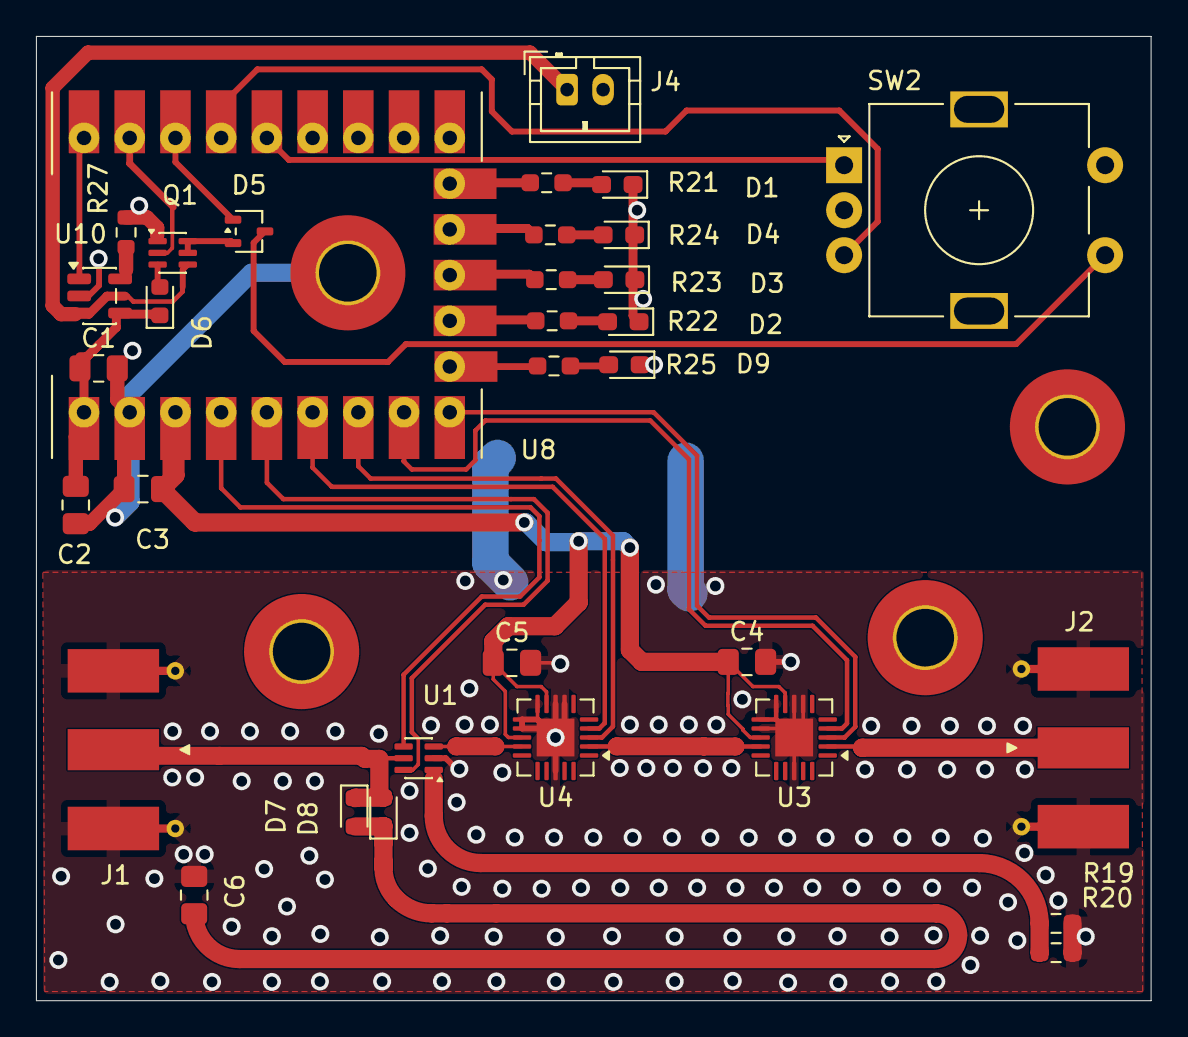
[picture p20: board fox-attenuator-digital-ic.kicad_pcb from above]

Board: 2 copper layers, 61.9 x 53.6 mm, 37 parts (0 on the bottom side), 35 nets.

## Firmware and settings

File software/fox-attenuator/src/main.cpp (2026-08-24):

#include "event.hpp"
#include "hardwareManager.hpp"
#include "inputListener.hpp"
#include "logicManager.hpp"
#include "watchdog.hpp"
#include <zephyr/kernel.h>

int main()
{
    auto wdt = Watchdog::Get();
    if (not wdt) {
        return -ENODEV;
    }

    wdt->Feed();

    msgbus::Bus eventBus;
    InputListener inputListener(eventBus);
    HardwareManager::Create(eventBus);
    LogicManager appLogic{eventBus};
    k_msleep(10);
    appLogic.Start();
    
    while (true) {
        wdt->Feed();
        k_msleep(1000);
    }

    return 0;
}

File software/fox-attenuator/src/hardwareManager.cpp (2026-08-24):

#include "hardwareManager.hpp"

#include "event.hpp"

#include <algorithm>
#include <optional>
#include <zephyr/drivers/gpio.h>
#include <zephyr/usb/usbd.h>

namespace
{
    K_THREAD_STACK_DEFINE(hardwareManagerStack, 2048);
    const gpio_dt_spec led0    = GPIO_DT_SPEC_GET(DT_NODELABEL(led9), gpios);
    const gpio_dt_spec led1    = GPIO_DT_SPEC_GET(DT_NODELABEL(led10), gpios);
    const gpio_dt_spec led2    = GPIO_DT_SPEC_GET(DT_NODELABEL(led11), gpios);
    const gpio_dt_spec led3    = GPIO_DT_SPEC_GET(DT_NODELABEL(led12), gpios);
    const gpio_dt_spec led4    = GPIO_DT_SPEC_GET(DT_NODELABEL(led13), gpios);
    const gpio_dt_spec pwrOff  = GPIO_DT_SPEC_GET(DT_NODELABEL(pwr_off_gpio), gpios);
    const gpio_dt_spec btnGpio = GPIO_DT_SPEC_GET(DT_NODELABEL(btn_gpio), gpios);
    const gpio_dt_spec clk1    = GPIO_DT_SPEC_GET(DT_ALIAS(bda_clk1), gpios);
    const gpio_dt_spec serin1  = GPIO_DT_SPEC_GET(DT_ALIAS(bda_serin1), gpios);
    const gpio_dt_spec clk2    = GPIO_DT_SPEC_GET(DT_ALIAS(bda_clk2), gpios);
    const gpio_dt_spec serin2  = GPIO_DT_SPEC_GET(DT_ALIAS(bda_serin2), gpios);
    const gpio_dt_spec le      = GPIO_DT_SPEC_GET(DT_ALIAS(bda_le), gpios);
    const gpio_dt_spec rfCtrl  = GPIO_DT_SPEC_GET(DT_ALIAS(rf_sw_ctrl), gpios);
    const gpio_dt_spec rfCtrlN = GPIO_DT_SPEC_GET(DT_ALIAS(rf_sw_ctrl_n), gpios);
    const device* ledStrip     = DEVICE_DT_GET(DT_ALIAS(led_strip));

    USBD_DEVICE_DEFINE(usbdevice, DEVICE_DT_GET(DT_NODELABEL(zephyr_udc0)), 0x2e8a, 0x000a);

    USBD_DESC_LANG_DEFINE(usbdlang);
    USBD_DESC_MANUFACTURER_DEFINE(usbdeviceManufacturer, "SP5YAM");
    USBD_DESC_PRODUCT_DEFINE(usbdeviceProduct, "Fox attenuator");

    // 500 mA declararion
    USBD_CONFIGURATION_DEFINE(usbdeviceConfig, USB_SCD_SELF_POWERED, 250, nullptr);

} // namespace

namespace
{
    std::optional<HardwareManager> hardwareManagerObj;
}

HardwareManager* HardwareManager::Create(msgbus::Bus& bus)
{
    if (not hardwareManagerObj) {
        hardwareManagerObj.emplace(Key{}, bus);
        if (hardwareManagerObj->initialized_) {
            return &hardwareManagerObj.value();
        }
        hardwareManagerObj = std::nullopt;
    }
    return nullptr;
}

bool isBitSet(uint8_t val, uint8_t bit)
{
    return (val & (1 << bit)) != 0;
}

void HardwareManager::Handle(const msgbus::events::LedMatrixSet& lm) noexcept
{
    const auto val = lm.value;
    gpio_pin_set_dt(&led0, isBitSet(val, 0) ? 1 : 0);
    gpio_pin_set_dt(&led1, isBitSet(val, 1) ? 1 : 0);
    gpio_pin_set_dt(&led2, isBitSet(val, 2) ? 1 : 0);
    gpio_pin_set_dt(&led3, isBitSet(val, 3) ? 1 : 0);
    gpio_pin_set_dt(&led4, isBitSet(val, 4) ? 1 : 0);
}
void HardwareManager::Handle(const msgbus::events::PowerOff& ph) noexcept
{
    SetPinPowerOff();
}
void HardwareManager::Handle(const msgbus::events::RgbLedSet& rgb) noexcept
{
    rgbLed_.SetColor(rgb.color);
}
void HardwareManager::Handle(const msgbus::events::ApplyAttenuationChange& aac) noexcept
{
    attenuator_.Apply(aac.value);
    const auto attenuator0Val = attenuator_.GetAttenuatorBits(0);
    const auto attenuator1Val = attenuator_.GetAttenuatorBits(1);
    SetAttenuator(attenuator0Val, attenuator1Val);

    if (attenuator_.GetBypass()) {
        RfSwitchSetPath(true);
    }
    else {
        RfSwitchSetPath(false);
    }

    msgBus_.Publish(msgbus::events::AttenuationInfo{.attenuationHalfDb    = attenuator_.GetAttenuation(),
                                                    .maxAttenuationHalfDb = Attenuator::GetMaxAttenuation(),
                                                    .bypass               = attenuator_.GetBypass()});
}
void HardwareManager::EnqueueEvent(const EventVariant& event) noexcept
{
    k_msgq_put(&msgQueue_, &event, K_NO_WAIT);
}

HardwareManager::HardwareManager(Key, msgbus::Bus& bus)
    : subLedMatrixSet_{*this}, subPowerHoldSet_{*this}, subRgbLedSet_{*this}, subApplyAttenuationChange_{*this},
      msgBus_(bus), rgbLed_(ledStrip)
{
    initialized_ = SetupHardware();
    if (not initialized_) {
        return;
    }

    bus.Subscribe(subLedMatrixSet_);
    bus.Subscribe(subPowerHoldSet_);
    bus.Subscribe(subRgbLedSet_);
    bus.Subscribe(subApplyAttenuationChange_);

    k_msgq_init(&msgQueue_, msgBuffer_.data(), sizeof(EventVariant), kQueueDepth);
    k_thread_create(&threadData_,
                    hardwareManagerStack,
                    K_THREAD_STACK_SIZEOF(hardwareManagerStack),
                    ThreadEntry,
                    this,
                    nullptr,
                    nullptr,
                    K_PRIO_COOP(7),
                    0,
                    K_NO_WAIT);
}

// helpers
namespace
{
    template <std::size_t N> bool IsReady(const std::array<const gpio_dt_spec*, N>& ary)
    {
        return std::ranges::all_of(
            ary.begin(), ary.end(), [](const gpio_dt_spec* item) { return gpio_is_ready_dt(item); });
    }

    template <std::size_t N> void SetInactive(const std::array<const gpio_dt_spec*, N>& ary)
    {
        std::ranges::for_each(ary.begin(), ary.end(), [](const gpio_dt_spec* item) {
            gpio_pin_configure_dt(item, GPIO_OUTPUT_INACTIVE);
        });
    }

    template <std::size_t N> void SetInput(const std::array<const gpio_dt_spec*, N>& ary)
    {
        std::ranges::for_each(
            ary.begin(), ary.end(), [](const gpio_dt_spec* item) { gpio_pin_configure_dt(item, GPIO_INPUT); });
    }
} // namespace

bool HardwareManager::SetupHardware() noexcept
{
    const std::array outputs = std::to_array(
        {&pwrOff, &led0, &led1, &led2, &led3, &led4, &le, &clk1, &clk2, &serin1, &serin2, &rfCtrl, &rfCtrlN});
    const std::array inputs = std::to_array({&btnGpio});

    if (not IsReady(inputs)) {
        return false;
    }
    if (not IsReady(outputs)) {
        return false;
    }
    SetInactive(outputs);
    SetInput(inputs);

    if (SetupUsb() < 0) {
        return false;
    }

    if (not rgbLed_.Ready()) {
        return false;
    }

    return true;
}
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

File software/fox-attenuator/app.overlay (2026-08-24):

#include <zephyr/dt-bindings/input/input-event-codes.h>

/ {
	chosen {
		zephyr,console = &cdc_acm_uart0;
		zephyr,shell-uart = &cdc_acm_uart1;
	};

	aliases {
		led-ws2812 = &led_strip;
		chg-status = &chg_stat_gpio;
		pwr-off = &pwr_off_gpio;
		btn0 = &btn_gpio;
		encoder0 = &encoder;

		bda-clk1 = &bda_clk1;
		bda-serin1 = &bda_serin1;
		bda-clk2 = &bda_clk2;
		bda-serin2 = &bda_serin2;
		bda-le = &bda_le;

		rf-sw-ctrl = &rf_sw_ctrl;
		rf-sw-ctrl-n = &rf_sw_ctrl_n;

	};

	leds {
		compatible = "gpio-leds";

		led9: led_9 {
			gpios = <&gpio0 9 GPIO_ACTIVE_HIGH>;
			label = "LED GP9";
		};

		led10: led_10 {
			gpios = <&gpio0 10 GPIO_ACTIVE_HIGH>;
			label = "LED GP10";
		};

		led11: led_11 {
			gpios = <&gpio0 11 GPIO_ACTIVE_HIGH>;
			label = "LED GP11";
		};

		led12: led_12 {
			gpios = <&gpio0 12 GPIO_ACTIVE_HIGH>;
			label = "LED GP12";
		};

		led13: led_13 {
			gpios = <&gpio0 13 GPIO_ACTIVE_HIGH>;
			label = "LED GP13";
		};
	};

	rf_switch {
		compatible = "gpio-leds";

		rf_sw_ctrl: rf_sw_ctrl {
			gpios = <&gpio0 28 GPIO_ACTIVE_HIGH>;
			label = "RF Switch CTRL (GP28)";
		};

		rf_sw_ctrl_n: rf_sw_ctrl_n {
			gpios = <&gpio0 29 GPIO_ACTIVE_LOW>;
			label = "RF Switch CTRL Inverse (GP29)";
		};
	};

	gpio_keys {
		compatible = "gpio-keys";

		chg_stat_gpio: chg_stat {
			gpios = <&gpio0 0 (GPIO_PULL_UP | GPIO_ACTIVE_LOW)>;
			label = "Charging Status";
			zephyr,code = <INPUT_KEY_0>;
		};

		btn_gpio: button_2 {
			gpios = <&gpio0 2 (GPIO_PULL_UP | GPIO_ACTIVE_LOW)>;
			label = "Encoder button";
			zephyr,code = <INPUT_KEY_ENTER>;
		};
	};

	pwr_ctrl {
		compatible = "gpio-leds";

		pwr_off_gpio: pwr_off {
			gpios = <&gpio0 1 GPIO_ACTIVE_LOW>;
			label = "Power Hold";
		};
	};

	bda4601_if {
		compatible = "gpio-leds";

		bda_clk1: bda_clk1 {
			gpios = <&gpio0 27 GPIO_ACTIVE_HIGH>;
			label = "BDA4601 CLOCK1 (GP27)";
		};

		bda_serin1: bda_serin1 {
			gpios = <&gpio0 26 GPIO_ACTIVE_HIGH>;
			label = "BDA4601 SERIN1 (GP26)";
		};

		bda_clk2: bda_clk2 {
			gpios = <&gpio0 15 GPIO_ACTIVE_HIGH>;
			label = "BDA4601 CLOCK2 (GP15)";
		};

		bda_serin2: bda_serin2 {
			gpios = <&gpio0 14 GPIO_ACTIVE_HIGH>;
			label = "BDA4601 SERIN2 (GP14)";
		};

		bda_le: bda_le {
			gpios = <&gpio0 8 (GPIO_ACTIVE_HIGH)>;
			label = "BDA4601 LE (GP8)";
		};
	};

	encoder: encoder {
		compatible = "gpio-qdec";
		gpios = <&gpio0 4 (GPIO_PULL_UP | GPIO_ACTIVE_HIGH)>, /* Phase A */
		        <&gpio0 3 (GPIO_PULL_UP | GPIO_ACTIVE_HIGH)>; /* Phase B */
		steps-per-period = <4>;
		sample-time-us = <200>;
		idle-timeout-ms = <100>;
		zephyr,axis = <0>;
		label = "Incremental Encoder";
	};

};

&uart0 {
	status = "disabled";
};

&zephyr_udc0 {
	cdc_acm_uart0: cdc_acm_uart0 {
		compatible = "zephyr,cdc-acm-uart";
	};

	cdc_acm_uart1: cdc_acm_uart1 {
		compatible = "zephyr,cdc-acm-uart";
	};
};

&pio0 {
	status = "okay";

	pio_ws2812: ws2812 {
		status = "okay";
		compatible = "worldsemi,ws2812-rpi-pio";
		bit-waveform = <3 3 4>;
		pinctrl-0 = <&ws2812_default>;
		pinctrl-names = "default";

		led_strip: led_strip {
			status = "okay";
			compatible = "worldsemi,ws2812-pb";
			chain-length = <1>;
			color-mapping = <LED_COLOR_ID_BLUE LED_COLOR_ID_RED LED_COLOR_ID_GREEN>;
			reset-delay = <64>;
		};
	};
};

&pinctrl {
	ws2812_default: ws2812_default {
		group1 {
			pinmux = <PIO0_P16>;
		};
	};
};

&clk_sys {
	clock-frequency = <DT_FREQ_M(48)>;
};

&clk_peri {
	clock-frequency = <DT_FREQ_M(48)>;
};

&vreg {
	raspberrypi,brown-out-detection;

	/* in uV
	 * Default: 860000 (0.86V).
	 * - 860000  (0.86V)
	 * - 903000  (0.903V)
	 * - 946000  (0.946V)
	 * - 989000  (0.989V)
	 * - 1032000 (1.032V)
	 */
	raspberrypi,brown-out-threshold = <1032000>;
};

&wdt0 {
	compatible = "raspberrypi,pico-watchdog";
	status = "okay";
};

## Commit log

2026-07-31 SCH + PCB
    [fox-attenuator-digital-ic.kicad_pcb, fox-attenuator-digital-ic.kicad_sch]
2026-09-11 Auto power off 1h
